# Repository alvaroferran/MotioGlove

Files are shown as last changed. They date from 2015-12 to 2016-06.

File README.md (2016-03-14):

MotioGlove
===================================================================

<p align="center">
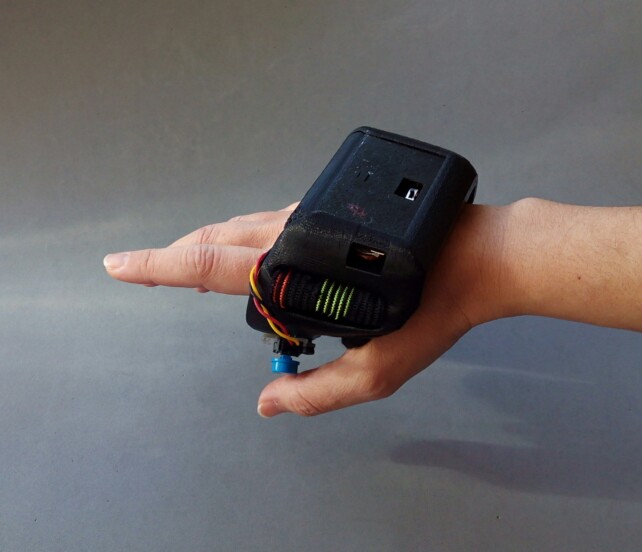
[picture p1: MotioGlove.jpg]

</p>

<br;>
<br;>
MotioGlove is an inertial remote controller. The board mounts an Atmega328P working at 8Mhz and 3.3V, a BC-04 bluetooth module, a [BNO055 IMU](https://github.com/bqlabs/BNO055) and a 1-cell Lipo Charger. The USB to UART converter is a CH340, so its driver must be downloaded.

<p align="center">
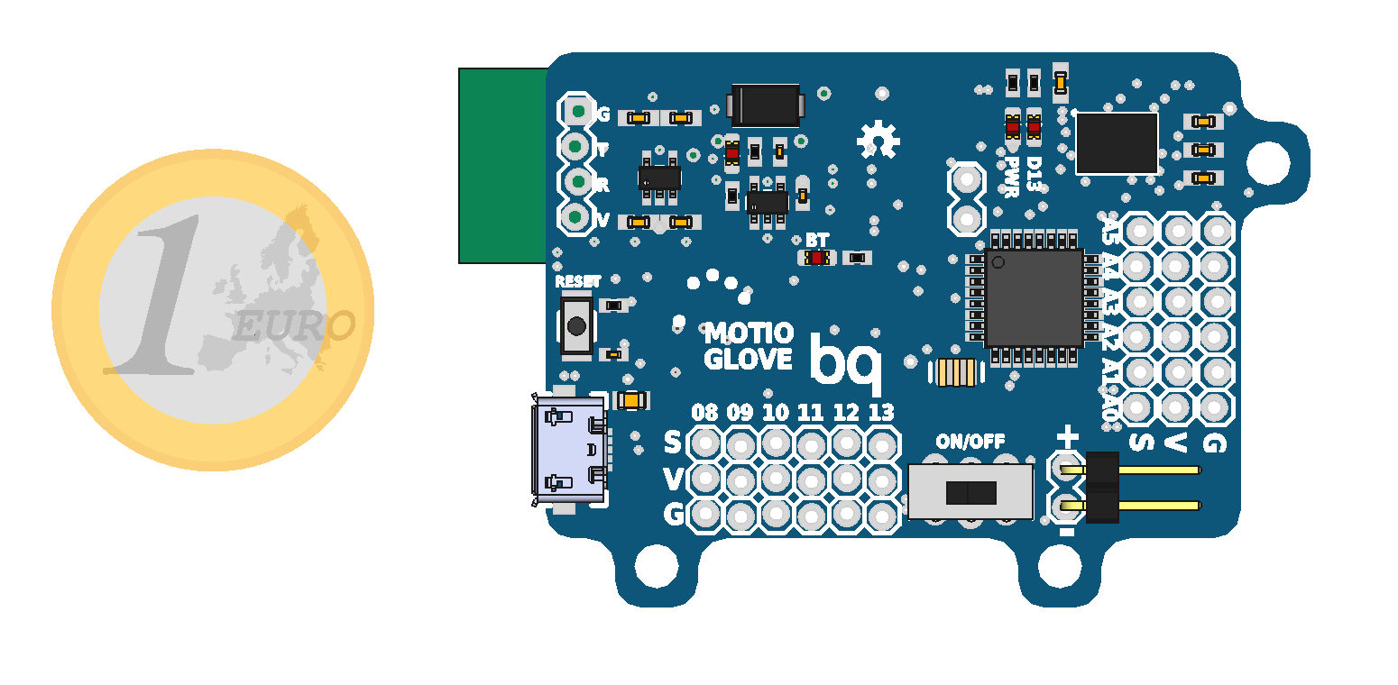
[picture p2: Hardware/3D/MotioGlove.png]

</p>

It has been used as a controller for [Loki](https://github.com/bqlabs/loki/tree/develop/loki), an omnidirectional robot, among others. Don't hesitate to contribute with your examples!

Attributions
--------------------------------------------------------------
 - [Alvaro Ferrán Cifuentes](https://github.com/alvaroferran)
  - HW & SW design

- [Sonia Verdú ](https://github.com/soniaverdu)
  - Mechanical design

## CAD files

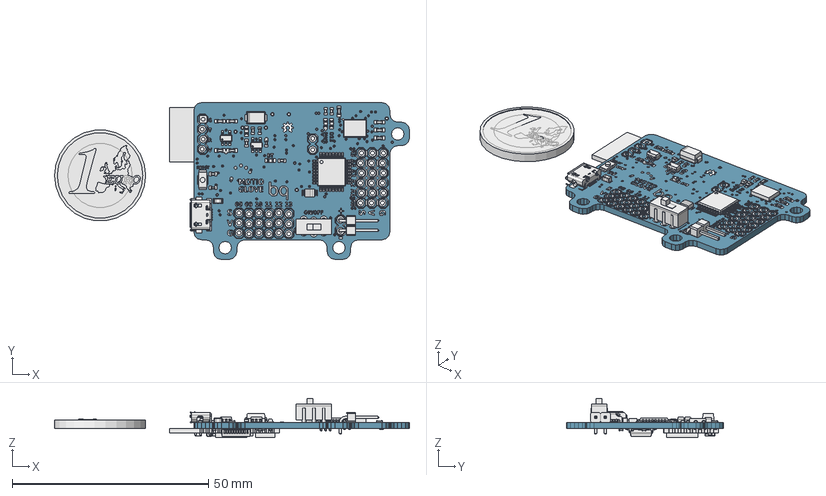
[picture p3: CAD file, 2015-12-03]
Hardware/3D/MotioGlove.fcstd
90.5 x 40.0 x 10.0 mm
Board
C15
C18
C20
C1
C2
C5
C6
C22
C23
R10
R11
R7
R8
R9
R6
R5
R16
R3
R4
R2
R24
R19
U2
U4
Y1
C16
C17
C19
C21
C4
C8
C3
C7
U3
IC3
LED3
LED2
LED1
LED4
SW1
SW2
Q3
U5
IC2
D2
F1
JP8
JP5
tPad_17
bPad_18
tPlace_21
bPlace_22
Euro
ShapeString
ShapeString001
ShapeString002
ShapeString003
ShapeString004
ShapeString005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

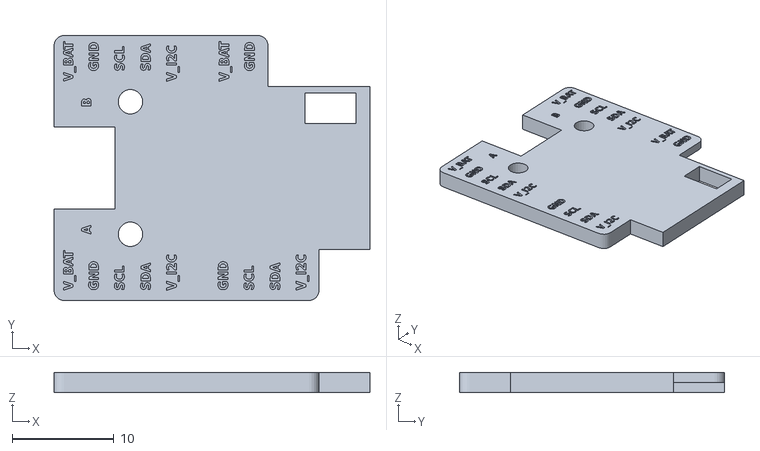
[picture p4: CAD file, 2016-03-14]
Hardware/3D/STL/cover.stl
31.0 x 26.0 x 2.00

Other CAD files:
Hardware/Outline/Outline.fcstd
Hardware/Outline/Outline.dxf

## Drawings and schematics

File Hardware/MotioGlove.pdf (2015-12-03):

## TXRXCTS RTS

# PIO(0) PIO(1) PIO(2) PIO(3) PIO(4) PIO(5) PIO(6) PIO(7) PIO(8) PIO(9) PIO(10) PIO(11)

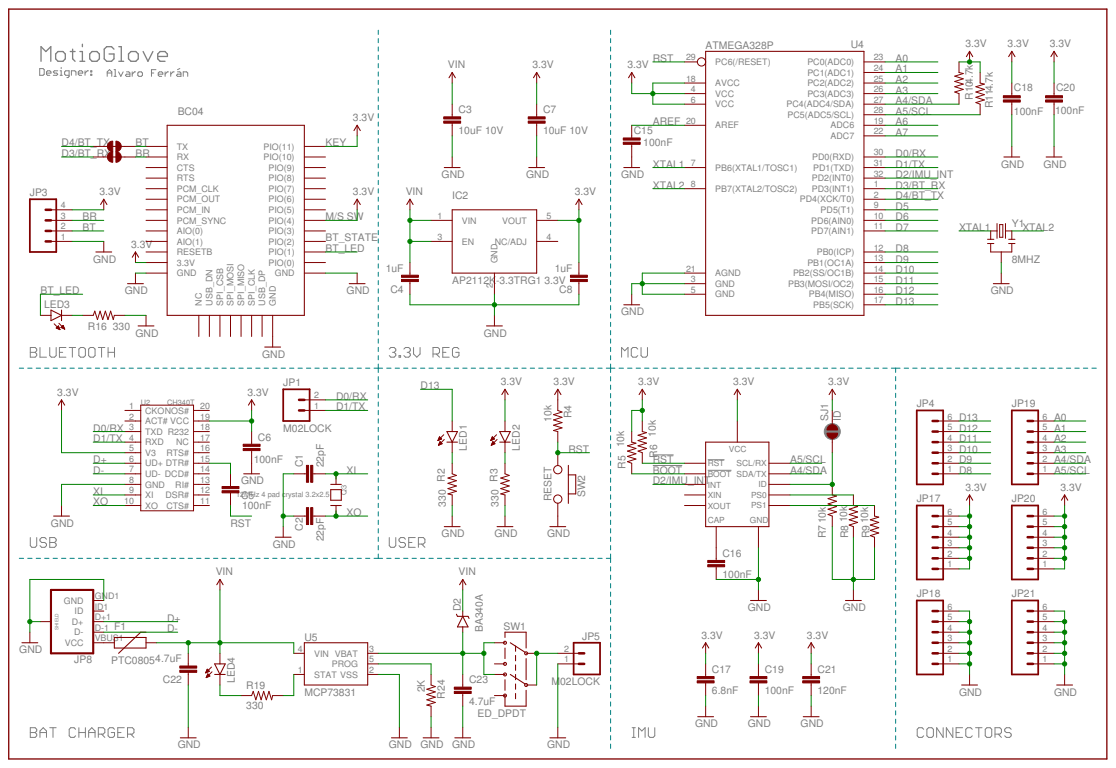
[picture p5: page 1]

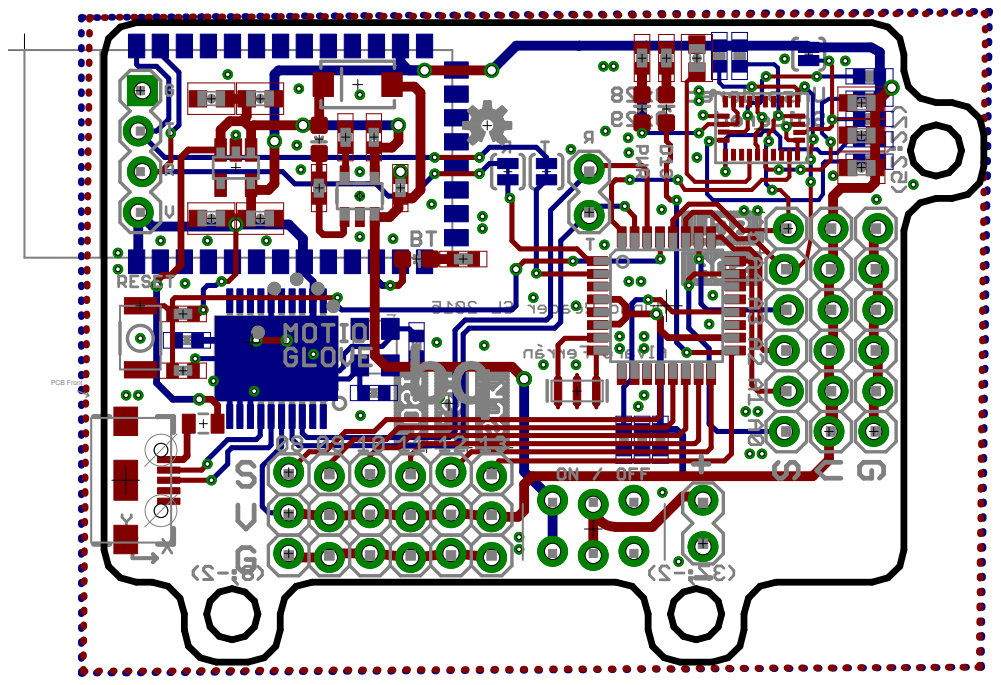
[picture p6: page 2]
1 PCB Front

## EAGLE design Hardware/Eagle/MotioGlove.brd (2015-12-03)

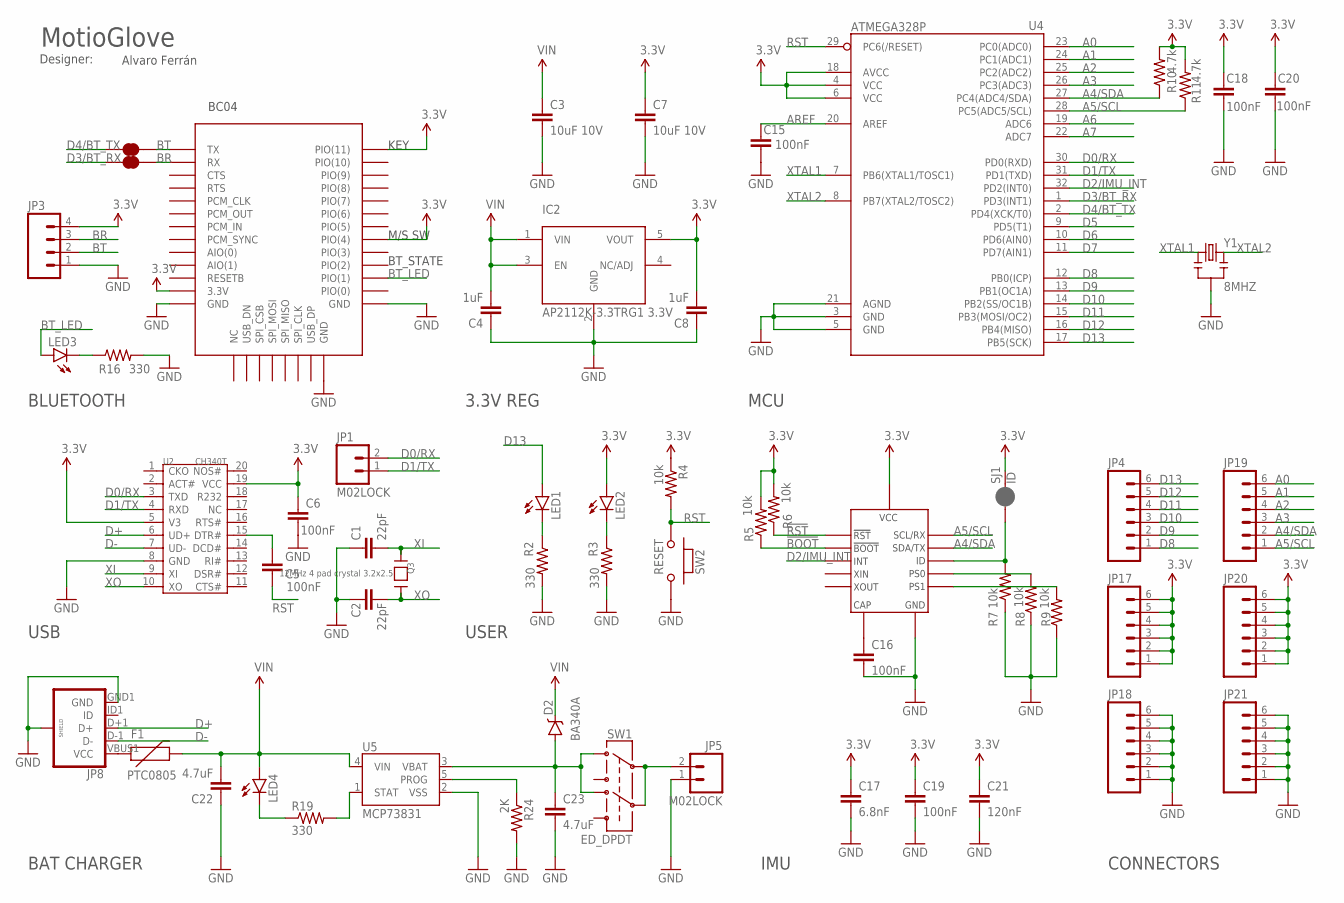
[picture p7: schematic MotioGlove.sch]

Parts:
C1, C2: 22pF; 0402-CAP
C3, C7: 10uF 10V; 0603-CAP
C4, C8: 1uF; 0603-CAP
C5, C6, C15, C18, C20: 100nF; 0402-CAP
C16, C19: 100nF; 0603-CAP
C17: 6.8nF; 0603-CAP
C21: 120nF; 0603-CAP
C22, C23: 4.7uF; 0402-CAP
D2: BA340A; SMA-DIODE
F1: PTC0805; 0805
IC2: AP2112K-3.3TRG1 3.3V; SOT23-5
IC3: BC04_BLUETOOTH; BC04
JP1, JP5: M02LOCK; 1X02_LOCK
JP3: M04LOCK; 1X04_LOCK
JP4, JP17, JP18, JP19, JP20, JP21: M06LOCK; 1X06_LOCK
JP8: USB_MICROB_PLUGCONN-11752; USB-B-MICRO-SMD_V03
LED1, LED2, LED3, LED4: LED0603; LED-0603
Q3: 12MHz 4 pad crystal 3.2x2.5; CRYSTAL_3.2X2.5
R: JUMPER-PAD-2-NC_BY_TRACE; PAD-JUMPER-2-NC_BY_TRACE_YES_SILK
R2, R3, R16, R19: 330; 0402-RES
R4, R5, R6, R7, R8, R9: 10k; 0402-RES
R10, R11: 4.7k; 0402-RES
R24: 2K; 0402-RES
SJ1: ID; PAD-JUMPER-2-NC_BY_PASTE_YES_SILK
SW1: ED_DPDT
SW2: RESET; 157SW
T: JUMPER-PAD-2-NC_BY_TRACE; PAD-JUMPER-2-NC_BY_TRACE_YES_SILK
U2: CH340T; SSOP20
U3: BNO055
U4: ATMEGA328P; TQFP32-08
U5: MCP73831; SOT23-5
Y1: 8MHZ; RESONATOR-SMD

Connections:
3.3V: C6.1, C7.1, C8.2, C17.1, C18.1, C19.1, C20.1, C21.1, IC2.5 (VOUT), IC3.P$12 (3.3V), IC3.P$27 (PIO(4)), IC3.P$34 (PIO(11)), JP3.4, JP17.1, JP17.2, JP17.3, JP17.4, JP17.5, JP17.6, JP20.1, JP20.2, JP20.3, JP20.4, JP20.5, JP20.6, LED2.A, R4.1, R5.2, R6.2, R10.2, R11.2, SJ1.2, U2.5 (V3), U2.19 (VCC), U3.3 (VCC), U3.28 (VCC), U4.4 (VCC), U4.6 (VCC), U4.18 (AVCC)
!BOOT: R5.1, U3.4 (BOOT)
!RST: R6.1, U3.11 (RST)
A0: JP19.6, U4.23 (PC0(ADC0))
A1: JP19.5, U4.24 (PC1(ADC1))
A2: JP19.4, U4.25 (PC2(ADC2))
A3: JP19.3, U4.26 (PC3(ADC3))
A4/SDA: JP19.2, R10.1, U3.20 (SDA/TX), U4.27 (PC4(ADC4/SDA))
A5/SCL: JP19.1, R11.1, U3.19 (SCL/RX), U4.28 (PC5(ADC5/SCL))
A6: U4.19 (ADC6)
A7: U4.22 (ADC7)
AREF: C15.1, U4.20 (AREF)
BR: IC3.P$2 (RX), JP3.3, R.2
BT: IC3.P$1 (TX), JP3.2, T.2
BT_LED: IC3.P$24 (PIO(1)), LED3.A
D0/RX: JP1.2, U2.3 (TXD), U4.30 (PD0(RXD))
D1/TX: JP1.1, U2.4 (RXD), U4.31 (PD1(TXD))
D2/IMU_INT: U3.14 (INT), U4.32 (PD2(INT0))
D3/BT_RX: R.1, U4.1 (PD3(INT1))
D4/BT_TX: T.1, U4.2 (PD4(XCK/T0))
D5: U4.9 (PD5(T1))
D6: U4.10 (PD6(AIN0))
D7: U4.11 (PD7(AIN1))
D8: JP4.1, U4.12 (PB0(ICP))
D9: JP4.2, U4.13 (PB1(OC1A))
D10: JP4.3, U4.14 (PB2(SS/OC1B))
D11: JP4.4, U4.15 (PB3(MOSI/OC2))
D12: JP4.5, U4.16 (PB4(MISO))
D13: JP4.6, LED1.A, U4.17 (PB5(SCK))
D+: JP8.D+1 (D+), U2.6 (UD+)
D-: JP8.D-1 (D-), U2.7 (UD-)
GND: C1.1, C2.1, C3.2, C4.1, C6.2, C7.2, C8.1, C15.2, C16.2, C17.2, C18.2, C19.2, C20.2, C21.2, C22.1, C23.2, IC2.2 (GND), IC3.P$13 (GND), IC3.P$21 (GND), IC3.P$22 (GND), JP3.1, JP5.1, JP8.GND1 (GND), JP8.SHIELD1 (SHIELD), JP8.SHIELD2 (SHIELD), JP8.SHIELD3 (SHIELD), JP18.1, JP18.2, JP18.3, JP18.4, JP18.5, JP18.6, JP21.1, JP21.2, JP21.3, JP21.4, JP21.5, JP21.6, R2.2, R3.2, R7.1, R8.1, R9.1, R16.2, R24.2, SW2.2, U2.8 (GND), U3.2 (GND), U3.10 (GND), U3.15 (GND), U3.16 (GND), U3.18 (GND), U3.25 (GND), U4.3 (GND), U4.5 (GND), U4.21 (AGND), U5.2 (VSS), Y1.2
unnamed: C5.1, U2.15 (DTR#)
unnamed: R7.2, SJ1.1, U3.17 (ID)
unnamed: JP5.2, SW1.2, SW1.5
unnamed: F1.1, JP8.VBUS1 (VCC)
unnamed: R8.2, U3.6 (PS0)
unnamed: R9.2, U3.5 (PS1)
unnamed: LED1.C, R2.1
unnamed: C16.1, U3.9 (CAP)
unnamed: R19.2, U5.1 (STAT)
unnamed: LED3.C, R16.1
unnamed: LED4.C, R19.1
unnamed: LED2.C, R3.1
PROG: R24.1, U5.5 (PROG)
RST: C5.2, R4.2, SW2.1, U4.29 (PC6(/RESET))
VBAT: C23.1, D2.A, SW1.1, SW1.4, U5.3 (VBAT)
VIN: C3.1, C4.2, C22.2, D2.C, F1.2, IC2.1 (VIN), IC2.3 (EN), LED4.A, U5.4 (VIN)
XI: C1.2, Q3.3, U2.9 (XI)
XO: C2.2, Q3.1, U2.10 (XO)
XTAL1: U4.7 (PB6(XTAL1/TOSC1)), Y1.1
XTAL2: U4.8 (PB7(XTAL2/TOSC2)), Y1.3

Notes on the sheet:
3.3V REG
USB
MCU
IMU
MotioGlove
Designer:
Alvaro Ferrán
USER
BAT CHARGER
BLUETOOTH
BC04
KEY
M/S SW
BT_STATE
CONNECTORS

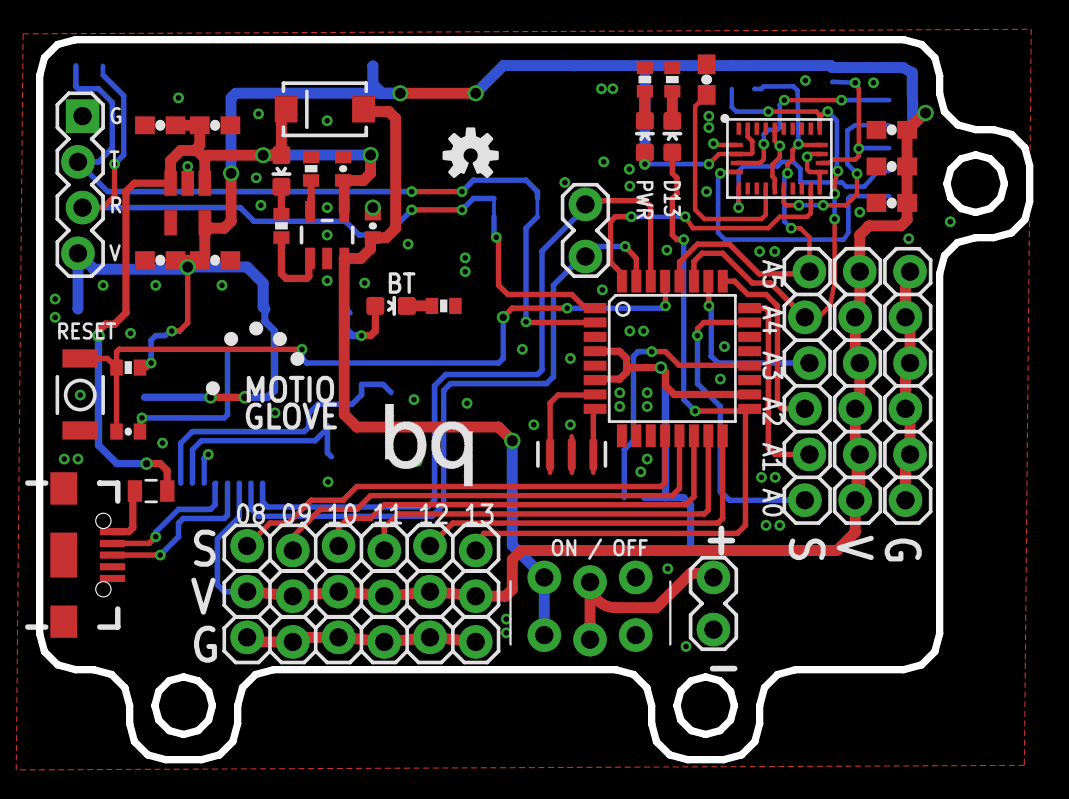
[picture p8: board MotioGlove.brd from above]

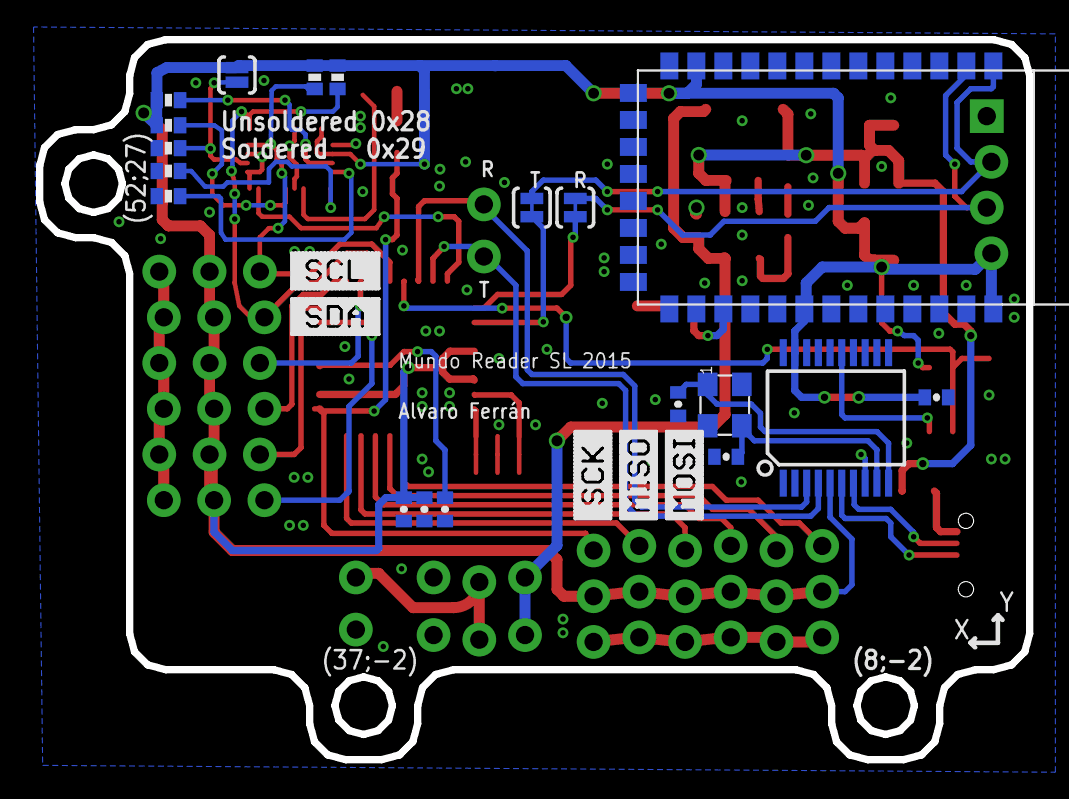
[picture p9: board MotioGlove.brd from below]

Board: 2 copper layers, 55.0 x 40.0 mm, 67 parts (24 on the bottom side), 47 nets.

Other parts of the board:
U$1: BQ_LOGO_1
U$2: S_SDA
U$3: OSHW-LOGO-S
U$4: BQ_LOGO_SMALL_2
U$5: S_SCL
U$6: S_MOSI
U$7: S_MISO
U$8: S_SCK

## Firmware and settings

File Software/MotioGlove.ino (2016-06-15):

#include "BNO055.h"
#include <Wire.h>
#include <SoftwareSerial.h>

SoftwareSerial mySerial(4, 3); // RX, TX

#define A 0X28  //I2C address selection pin LOW
#define B 0x29  //                          HIGH

BNO055 sensor(A);

int pinButton=10;



void setup(){
    Wire.begin();
    mySerial.begin(19200);
    Serial.begin(19200);
    sensor.init();
    pinMode(pinButton, INPUT_PULLUP);
}



double map(double vx, double v1, double v2, double n1, double n2){
    // v1 start of range, v2 end of range, vx the starting number between the range
    double percentage = (vx-v1)/(v2-v1);
    // n1 start of new range, n2 end of new range
    return (n2-n1)*percentage+n1;
}



void normalizeAxes(double *aAxes){
    int sensorMin=10, sensorMax=40;
    double aX=aAxes[0];
    double aY=aAxes[1];
    //Resting zone
    if(aX<sensorMin && aX>-sensorMin) aX=0;
    if(aY<sensorMin && aY>-sensorMin) aY=0;
    //Map from angles to aX values between -1 and 1
    if(aX<-sensorMin) aX=map(aX,-sensorMin,-sensorMax,0,1);
    if(aX>sensorMin)  aX=map(aX,sensorMin,sensorMax,0,-1);
    if(aY<-sensorMin) aY=map(aY,-sensorMin,-sensorMax,0,1);
    if(aY>sensorMin)  aY=map(aY,sensorMin,sensorMax,0,-1);
    aY=map(aY,-1,1,1,-1);
    //Limit maximum values in all axes
    if(aX<-1) aX=-1;
    if(aX>1)  aX=1;
    if(aY<-1) aY=-1;
    if(aY>1)  aY=1;

    aAxes[0]=aX;
    aAxes[1]=aY;
}



void loop(){
    double x,y,z;
    int btn;

    sensor.readEul();
    x=sensor.euler.y;
    y=sensor.euler.z;

    double axes[2];
    axes[0]=x; axes[1]=y;
    normalizeAxes(&axes[0]);
    x=axes[0]; y=axes[1];

    btn=digitalRead(pinButton);
    //If button pressed set roll angle to yaw
    if(btn==0){
        z=y;
        y=0;
        x=0;
    }
    else z=0;

    // Send values
    mySerial.print("(");
    mySerial.print(x,2);
    mySerial.print(";");
    mySerial.print(y,2);
    mySerial.print(";");
    mySerial.print(z,2);
    mySerial.println(")");

    delay(100);
}

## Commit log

2015-12-03 Project added
    [MotioGlove.brd, MotioGlove.fcstd, MotioGlove.sch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]
2016-03-14 json added
    [cover.stl]

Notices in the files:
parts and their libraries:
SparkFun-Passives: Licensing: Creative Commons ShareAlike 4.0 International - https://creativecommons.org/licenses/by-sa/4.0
